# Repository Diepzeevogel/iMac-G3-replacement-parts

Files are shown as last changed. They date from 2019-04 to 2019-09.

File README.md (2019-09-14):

# iMac G3 replacement parts
These files are an attempt at recreating some of the parts of an iMac G3 for a casemod.
My inner bezel shattered while disassembling, so a replacement was needed. 
I will also add mounting points for an LCD display.

This build is finished. Instructions and why not to do this can be found on hackaday.io: https://hackaday.io/project/160719-imac-g3-casemod

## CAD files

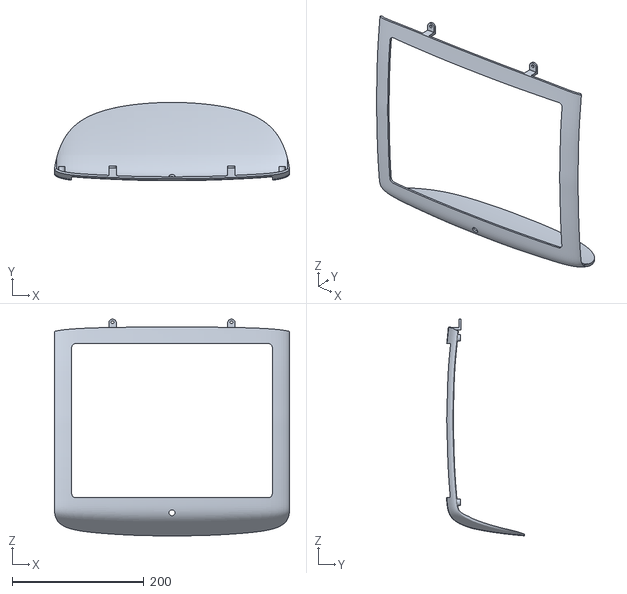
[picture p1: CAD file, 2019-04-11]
Bezel/FULL.stl
356.7 x 118.6 x 329.0

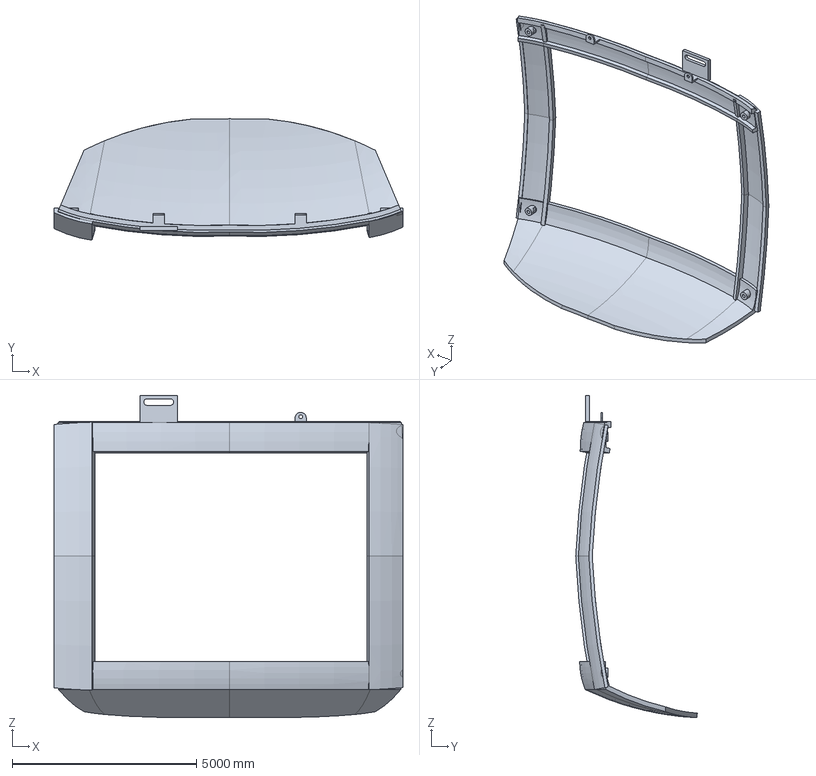
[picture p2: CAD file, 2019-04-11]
Bezel/Original by dahmze1/bezel04_dahmze1.stp
9461.5 x 3296.0 x 8742.2 mm

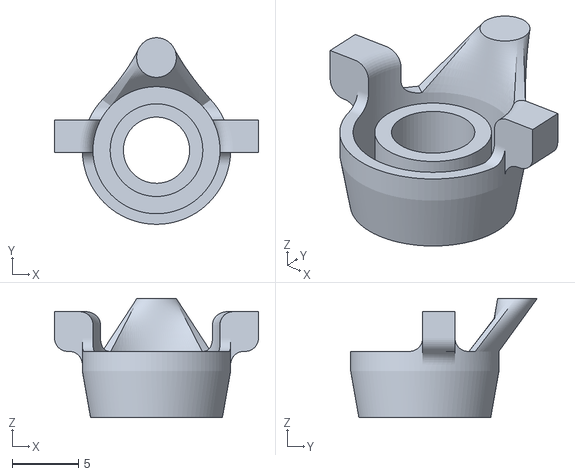
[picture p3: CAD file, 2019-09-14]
Bezel/PWR_BTN.stl
15.4 x 14.1 x 9.00

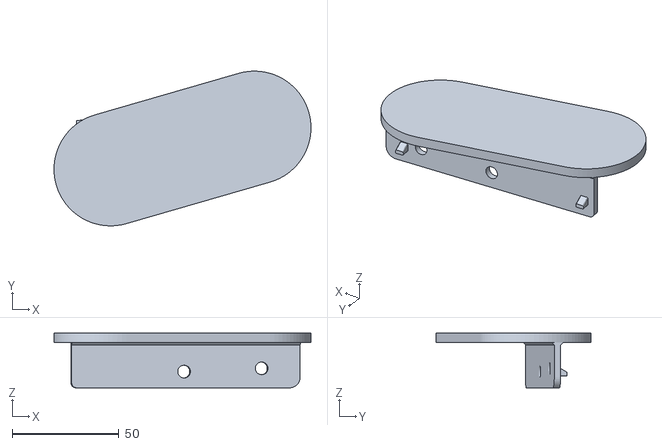
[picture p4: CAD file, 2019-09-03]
IO/Mount.stl
120.3 x 72.4 x 25.6

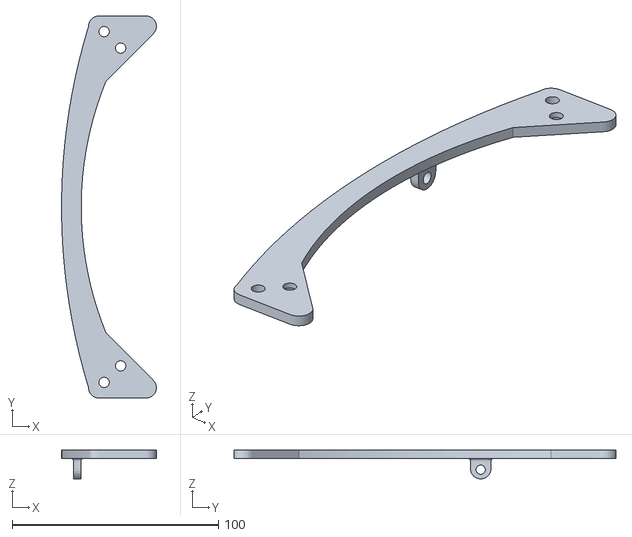
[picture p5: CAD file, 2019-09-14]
Mounts/200mm fan/fan_mount_top.stl
46.0 x 185.2 x 14.0

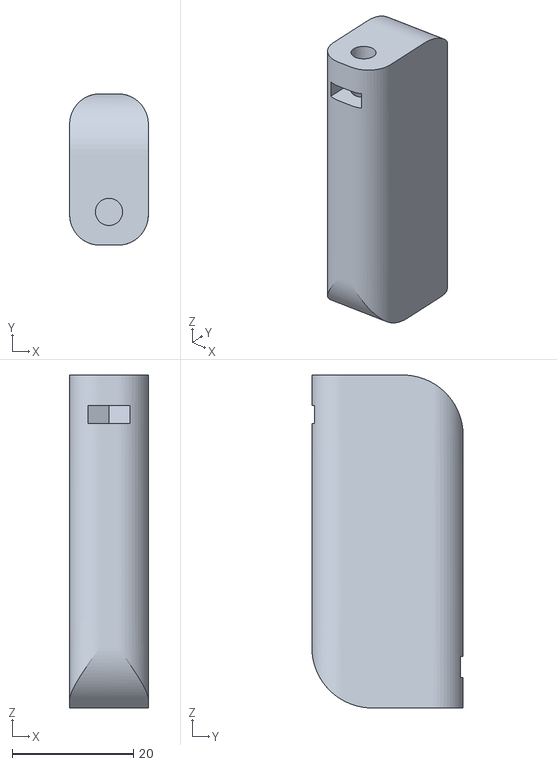
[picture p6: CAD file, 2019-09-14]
Mounts/Bottom Chassis/btm_connection.stl
13.0 x 25.0 x 55.0

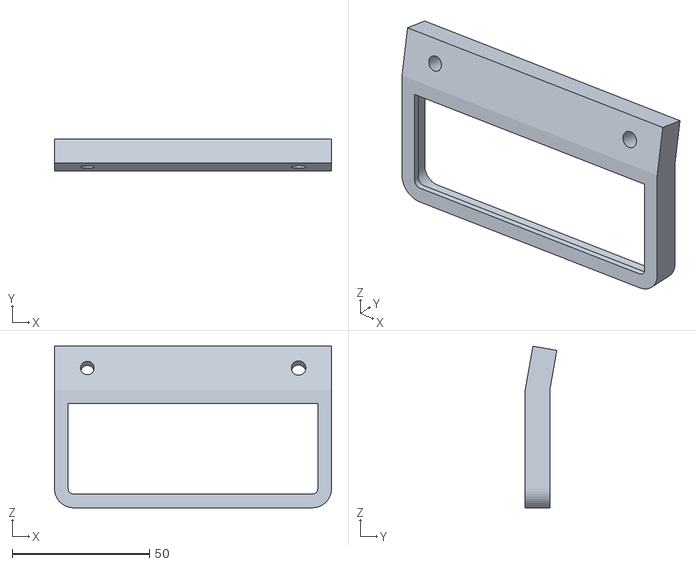
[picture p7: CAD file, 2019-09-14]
Mounts/GPU/Back bracket.stl
101.0 x 11.5 x 58.9

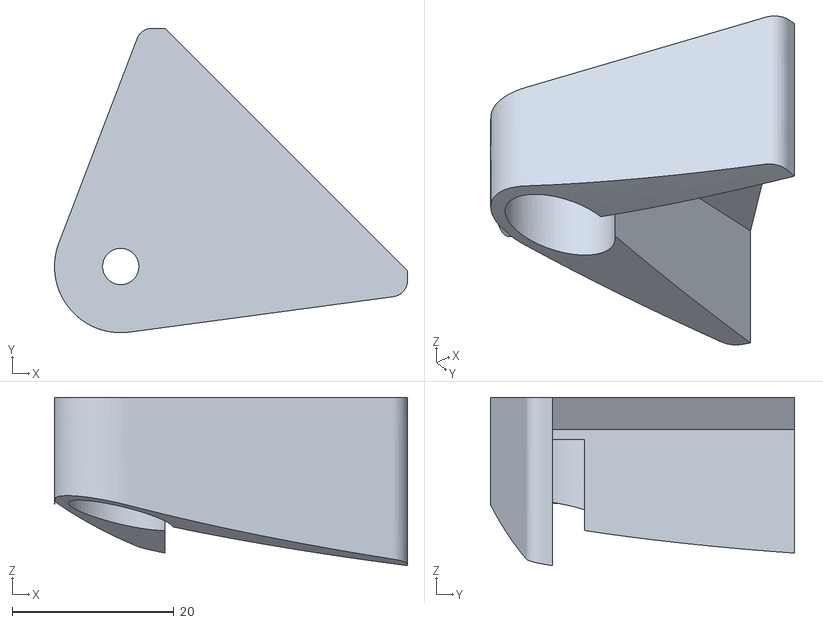
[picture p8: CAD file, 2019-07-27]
Mounts/LCD mounts/B_R_LCD.stl
43.7 x 37.7 x 20.8

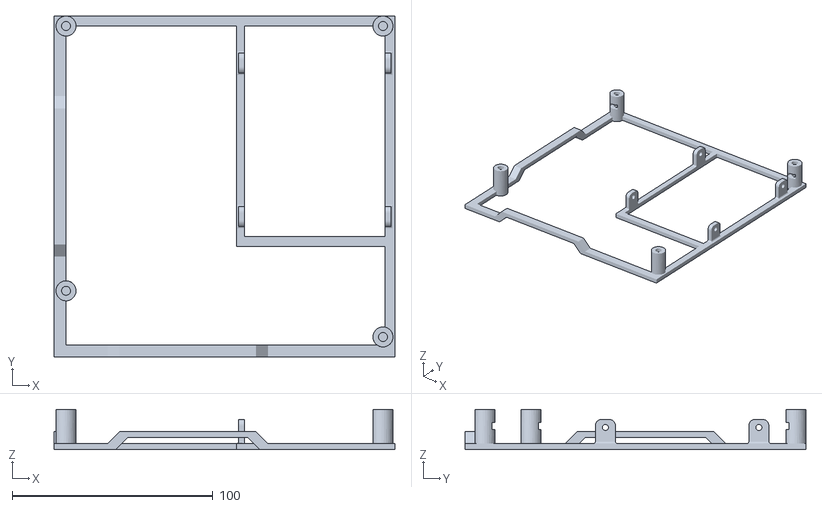
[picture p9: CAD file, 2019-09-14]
Mounts/Motherboard+HDD/Mini-ITX.stl
170.0 x 170.0 x 20.0

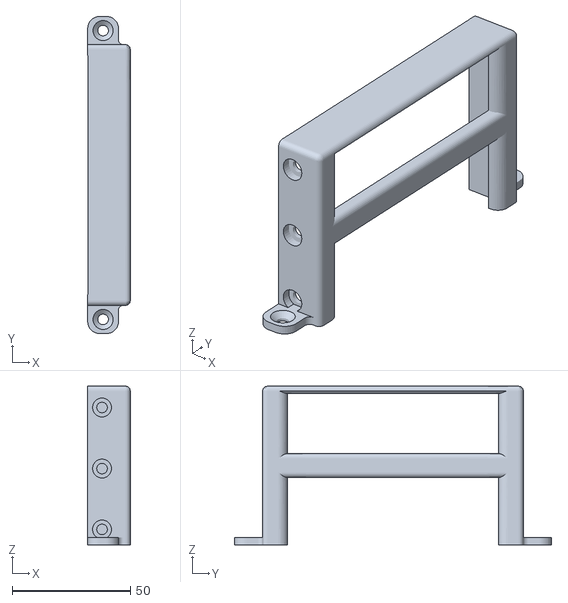
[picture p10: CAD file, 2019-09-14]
Mounts/SFX PSU to VESA/PSU2.stl
18.0 x 133.9 x 67.0

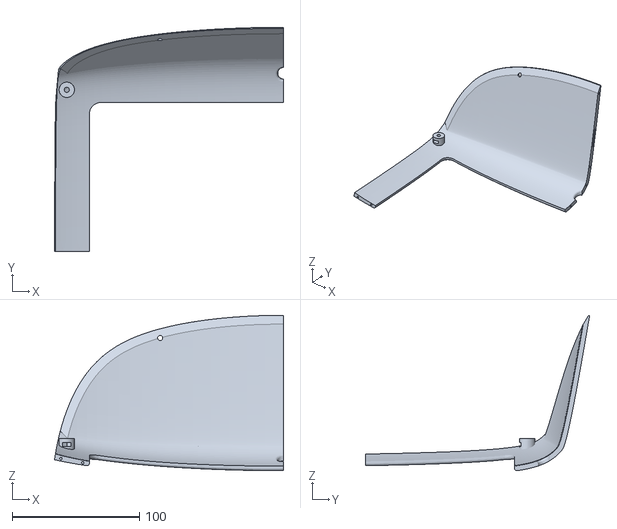
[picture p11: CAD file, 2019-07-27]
Bezel/TOP_RIGHT.stl
179.6 x 176.0 x 121.9

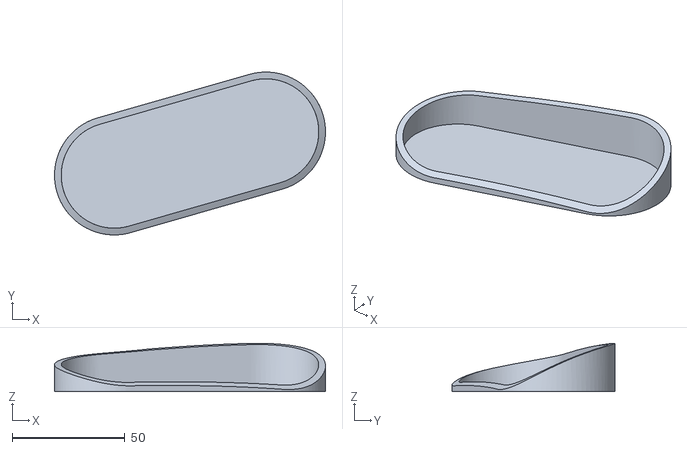
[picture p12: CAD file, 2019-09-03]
IO/IO Shield.stl
120.3 x 72.3 x 21.5

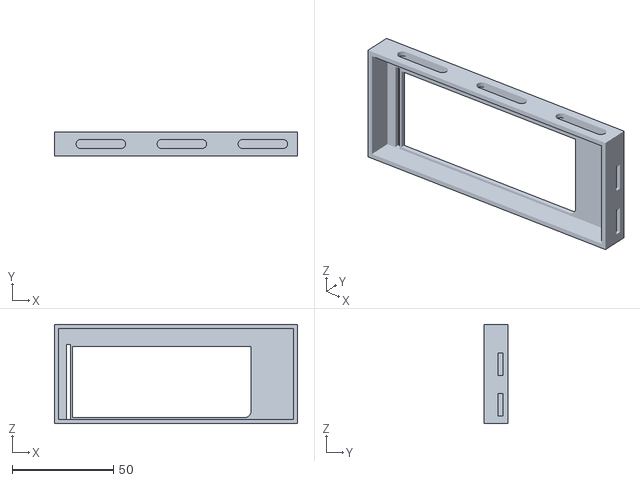
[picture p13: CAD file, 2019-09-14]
Mounts/GPU/Front bracket.stl
120.0 x 12.0 x 49.0

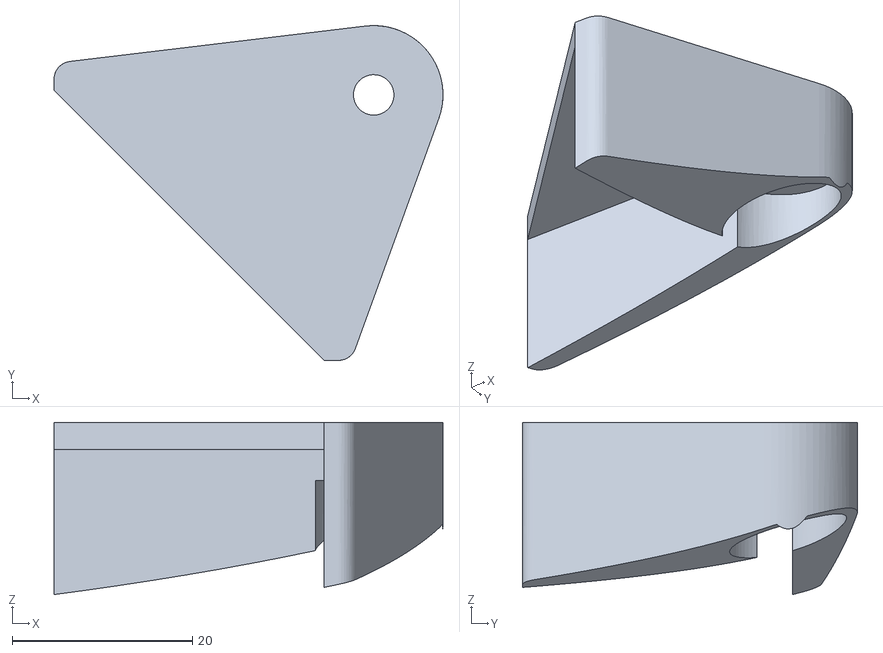
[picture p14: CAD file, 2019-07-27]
Mounts/LCD mounts/T_L_LCD.stl
43.2 x 37.2 x 19.1

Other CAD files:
Mounts/SFX PSU to VESA/PSU1.stl
Bezel/BOTTOM_LEFT.stl
IO/Mount_Cutouts.stl
Mounts/200mm fan/fan_mount_btm.stl
Bezel/BOTTOM_RIGHT.stl
Bezel/Original by dahmze1/bezel04_dahmze1.stl
Bezel/TOP_LEFT.stl
IO/IO Shield_cutouts.stl
IO/IO_shield.f3d
Mounts/200mm fan/fan_mount_top (1).stl
Mounts/Bottom Chassis/Bottom connector.f3d
Mounts/GPU/GPU mount.f3d
Mounts/GPU/GPU protection.stl
Mounts/GPU/GPU_mount.f3d
Mounts/LCD mounts/B_L_LCD.stl
Mounts/LCD mounts/T_R_LCD.stl
Mounts/Motherboard+HDD/Mobo+HDD.f3d
Mounts/SFX PSU to VESA/PSU.f3d
Mounts/SFX PSU to VESA/VESA1.stl
Mounts/SFX PSU to VESA/VESA2.stl
Mounts/SFX PSU to VESA/VESA3.stl
Mounts/SFX PSU to VESA/VESA4.stl

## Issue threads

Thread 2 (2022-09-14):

Question about inner bezel

8lall0, 2022-09-14:
Hi, i have a G3 with the inner bezel completely destroyed thanks to the worst packaging ever.
Can your inner bezel model replace it?

Thanks!

MichalNemecek, 2022-12-31:
it's not the packaging's fault, mine was packaged in two or three layers of bubble wrap and cardboard, and the inner bezel was still shattered when I unpacked it.

Anyway, I would also like to know if this model is compatible with a stock CRT. I don't want a LCD in my G3.

cfryerdev, 2023-07-13:
This also happened to me, a 2000 iMac G3 DV 450... I had to add spacers for the bezel to fit the mounting screws as the designs above are too short, and a mount for the larger mic to fit into and mount. Note: I got lazy and just sanded the edges to match the curve for the mic mount though.

Standoffs: https://github.com/cfryerdev/iMac-G3-replacement-parts/blob/master/Mounts/CRT/iMac_G3_Standoffs.stl

Mic Mount: https://github.com/cfryerdev/iMac-G3-replacement-parts/blob/master/Mounts/Mic/iMac_G3_Mic_Mount.stl

crozone, 2023-09-14:
I have an intact bezel and a 3D scanner, would a reference STL of the original part be useful?

cfryerdev, 2023-09-14:
That would be awesome

8lall0, 2024-01-17:
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

Do you have pictures on how did you mount the crt?

CelvinBraun, 2025-03-01:
> I have an intact bezel and a 3D scanner, would a reference STL of the original part be useful?

Did you ever had the chance to do the 3D scan?

CelvinBraun, 2025-03-01:
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

@cfryerdev - I would be interested in this as well.

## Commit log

2019-04-11 Original + First attempt
    [BOTTOM_LEFT.stl, BOTTOM_RIGHT.stl, TOP_LEFT.stl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]
2019-04-11 Started from scratch + added design files
    [BOTTOM_LEFT.stl, BOTTOM_RIGHT.stl, FULL.stl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]
2019-04-11 Added flat brim for LCD to rest against
    [BOTTOM_LEFT.stl, BOTTOM_RIGHT.stl, TOP_LEFT.stl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]
2019-04-11 Revision 3
    Notes after second attempt taken in to account. Only left side as .stl
    [BOTTOM_LEFT.stl, TOP_LEFT.stl]
2019-04-11 Added IO shield v1
    [BOTTOM_LEFT.stl, BOTTOM_RIGHT.stl, FULL.stl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]
2019-04-11 Changed orientation of stl files
    [BOTTOM_LEFT.stl, BOTTOM_RIGHT.stl, TOP_LEFT.stl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]
2019-04-12 IO larger after print too small
    [IO Shield.stl, IO_shield.f3d]
2019-04-12 Revision 4
    Left and right edges about 6mm lower.
    Lower mounting point 1mm lower, 1.5mm thinner.
    [BOTTOM_LEFT.stl, BOTTOM_RIGHT.stl, TOP_LEFT.stl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]
2019-04-12 Updated changes after revision 3.
    Printing r4 atm (bottom left)
2019-04-19 Less high, thinner top curve. Added first attempt at power button
    [BOTTOM_LEFT.stl, BOTTOM_RIGHT.stl, PWR_BTN.stl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]
2019-04-21 Countersunk holes on top, ridges to keep power button in place
    [BOTTOM_RIGHT.stl, TOP_LEFT.stl, TOP_RIGHT.stl]
2019-05-06 IO shield v2 printed.
    [IO Shield.stl]
2019-05-24 Complete redo, based on photogrammetry 3d scan
    [BOTTOM_LEFT.stl, BOTTOM_RIGHT.stl, TOP_LEFT.stl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]
2019-05-24 Re-added chamfer on top parts, still untested
    [TOP_LEFT.stl, TOP_RIGHT.stl]
2019-05-24 Holes on top 190mm apart
    Printed new version, fits well enough to use as final.
2019-05-25 Split button from bottom right
    [BOTTOM_RIGHT.stl]
2019-06-03 9° angle on power button face
    [BOTTOM_RIGHT.stl]
2019-06-03 Added IO (USB A, USB C, HDMI, DP, 3.5, RJ45)
    [IO Shield.stl, IO_shield.f3d]
2019-06-06 Imported 3D scan of inside curve for IO shield.
    Printed but didn't line up. Not final.
    [IO Shield.stl, IO_shield.f3d]
2019-06-07 Complete redo IO curve
    [IO Shield.stl]
2019-06-08 Untested mount for IO shield
    [IO Shield.stl, Mount.stl]
2019-06-15 Partly tested mount for IO. Holes are ok, angle might need work
    [IO Shield.stl, Mount.stl]
2019-07-04 Mounting plate for IO shield fits with correct angle.
    [Mount.stl]
2019-07-05 Unprinted changes to power button and top height
    [BOTTOM_LEFT.stl, BOTTOM_RIGHT.stl, TOP_LEFT.stl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]
2019-07-05 IO mount pegs up 1mm and removed extra hole for printability
    [Mount.stl]
2019-07-19 Top mount holes moved by a couple mm
    [BOTTOM_LEFT.stl, BOTTOM_RIGHT.stl, TOP_LEFT.stl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]
2019-07-19 Fixed missing hole in B_R
    [BOTTOM_RIGHT.stl]
2019-07-19 B_R Thicker and PWR_BTN hole slightly larger
    [BOTTOM_RIGHT.stl]
2019-07-27 Moved mounting positions for LCD and made brackets
    [BOTTOM_LEFT.stl, BOTTOM_RIGHT.stl, B_L_LCD.stl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]
2019-07-27 Custom cutouts in IO shield mount for my specific cables. Unfinished
    [IO Shield.stl, Mount_Cutouts.stl]
2019-09-03 Bezel and IO shield (+mount) tested and finished.
    [IO Shield.stl, IO Shield_cutouts.stl, Mount.stl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]
2019-09-03 Top 200mm fan rotating mount (printed but untested)
    [fan_mount_btm.stl, fan_mount_top (1).stl, fan_mount_top.stl]
2019-09-03 Bottom of chassis - to close everything up + 60mm fan mount
    [Bottom connector.f3d, btm_connection.stl, fan_mount.stl]
2019-09-03 Moved LCD mounting brackets
    [B_L_LCD.stl, B_R_LCD.stl, T_L_LCD.stl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]
2019-09-03 SFX PSU to VESA mount
    [PSU.f3d, PSU1.stl, PSU2.stl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]
2019-09-03 Motherboard and HDD mount with cable management. Based on whitewolf's design
    [Mini-ITX.stl, Mobo+HDD.f3d]
2019-09-14 Final bottom connectors
    [Bottom connector.f3d, btm_connection.stl, fan_mount.stl]
2019-09-14 Final 200mm fan mount
    [fan_mount_btm.stl, fan_mount_top (1).stl, fan_mount_top.stl]
2019-09-14 FInal GPU mount
    [Back bracket.stl, Front bracket.stl, GPU mount.f3d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]
2019-09-14 Final power button
    [PWR_BTN.stl]
2019-09-14 Final motherboard mount
    [Mini-ITX.stl, Mobo+HDD.f3d]
2019-09-14 PSU mount final untested - might need work
    [PSU.f3d, PSU1.stl, PSU2.stl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]
2019-09-14 fixed an oopsie in gpu bracket
    [Back bracket.stl, GPU mount.f3d]
